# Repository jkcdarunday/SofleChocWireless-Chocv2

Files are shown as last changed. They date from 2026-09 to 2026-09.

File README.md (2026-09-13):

# Sofle Choc Wireless — Choc v2 PCB prototype

Revision: CV2-P1, 2026-09-13. Based on
[db-ok/SofleChocWireless](https://github.com/db-ok/SofleChocWireless/tree/aae7cc0ac5ca563dab8222320ae8749ed1911e56),
commit `aae7cc0ac5ca563dab8222320ae8749ed1911e56`.

This project modifies the reversible Sofle Choc Wireless PCB for Kailh Choc v2
(PG1353) switch mounting. The PCB, three switch footprint definitions, and
minimum track-width constraint have been changed. Nearby traces and vias have
been rerouted around the enlarged holes.

**This is an unbuilt prototype.** Connectivity passes KiCad's check, but the
board still has DRC findings described in `VALIDATION.md`. Review those findings
and test physical fit before ordering an assembled keyboard or a production run.

## AI-Generated Changes Disclosure

The changes in this fork were generated using ChatGPT 6 Astra Max and have not been independently reviewed or tested.

## Open the design

Extract the complete ZIP, then open:

`SofleChocWireless/PCB/SofleKeyboard.kicad_pro`

Use KiCad 7 or newer. The routed board is
`SofleChocWireless/PCB/SofleKeyboard.kicad_pcb`; the schematic is alongside it.
Keep the folder structure so the project-local library paths resolve. Standard
KiCad libraries may be needed to edit or replace other components. Footprints
are embedded in the PCB, including the revised switch geometry.

The source schematic is electrically unchanged. No firmware matrix changes are
required by these mechanical switch changes.

## PCB changes

| Feature | Revised geometry |
| --- | --- |
| Switch center hole | 5.0 mm nonplated hole at each of 30 positions per half |
| Fixing-pin relief | Two mirrored 1.5 × 2.0 mm nonplated slots per switch; 60 total |
| Ordinary switch slot centers | Local coordinates (−5, 5.15) and (5, 5.15) mm |
| Optional encoder-position switch SW25 | Slots at local (−5, −5.15) and (5, −5.15) mm, matching its reversed switch orientation |
| Minimum track width | 0.15 mm, with new route sections using this width |
| Copper clearance constraint | Existing 0.20 mm minimum retained |
| Hole clearance constraint | Existing 0.25 mm minimum retained |

The 3.4 mm switch center holes were enlarged. At the 29 ordinary hotswap
positions, the old small boss holes were replaced by the fixing-pin slots.
SW25 received the two slots as well. Slot orientation follows each footprint,
including the angled thumb switches. Both mirrored positions are included for
the reversible PCB.

Electrical pad positions, sizes, layers, net names, and component positions
match the original board. Routing changes affect nearby matrix, LED, and ground
connections. Copper zones were refilled after rerouting. Ground vias were moved,
added, or removed as needed to retain connectivity around the new holes.

The three updated library footprints are in
`SofleChocWireless/PCB/SofleChoc.pretty/`:

- `Choc_Hotswap_SK6812MiniE_BiggerHSPads.kicad_mod` — 25 placements.
- `Choc_Hotswap_SK6812MiniE_BiggerHSPads_Column1.kicad_mod` — 4 placements.
- `Kailh-PG1350-1u-reversible-SK6812MiniE_MODIFIED.kicad_mod` — SW25.

Their original names are retained so existing schematic and board references
continue to resolve. Other footprint variants in the bundled libraries were
not converted to Choc v2.

## Assembly and fabrication

The original 29 hotswap positions and optional switch/encoder position are
retained. The existing wireless controller, battery, display, encoder, and LED
circuits are retained.

The center-hole and fixing-slot geometry targets PG1353, with slot relief
cross-checked against the PG1353S drawing. Physical compatibility has not been
tested with either variant. Choc v1 fit is also unverified after replacing the
original boss holes.

The case and plate files are included unchanged as reference geometry. Check
plate thickness, switch retention, keycap clearance, and standoff heights
against the exact switch variant and keycaps you intend to use. The existing
plate file settings are not a Choc v2 assembly specification.

Choose a PCB process that supports the project's 0.15 mm traces and routed
nonplated slots. Review the remaining DRC findings, inspect both copper layers
around the switch openings, and regenerate Gerbers and drill files from this
modified board after review. Confirm that the drill output contains the slots.
No fabrication exports are included in this package.

Prototype checks should cover switch seating on both PCB orientations, hotswap
socket clearance, matrix operation, wireless power operation, and LED operation
under the intended load. These have not been physically tested.

## Design references

- [Upstream source and build guide](https://github.com/db-ok/SofleChocWireless/blob/aae7cc0ac5ca563dab8222320ae8749ed1911e56/docs/build_guide_choc_wireless.md).
- [Kailh PG1353 datasheet, archived by Keyboardio](https://github.com/keyboardio/keyswitch_documentation/blob/323ea47b7b90550327231fa311a2762b1308661a/datasheets/Kailh/CPG135301D02.pdf).
- [Kailh PG1353S datasheet](https://www.kailhswitch.com/uploads/15927/files/CPG1353S01D02-01-data-sheet.pdf).
- [ai03 PG1353 hotswap footprint cross-check](https://github.com/ai03-2725/MX_V2/blob/0b379eebbeb66c7fd6e82e400b47958ad695614e/Kailh_PG1353_Hotswap.pretty/Kailh-PG1353-Hotswap-1U.kicad_mod).

The upstream license is included in `LICENSE`.

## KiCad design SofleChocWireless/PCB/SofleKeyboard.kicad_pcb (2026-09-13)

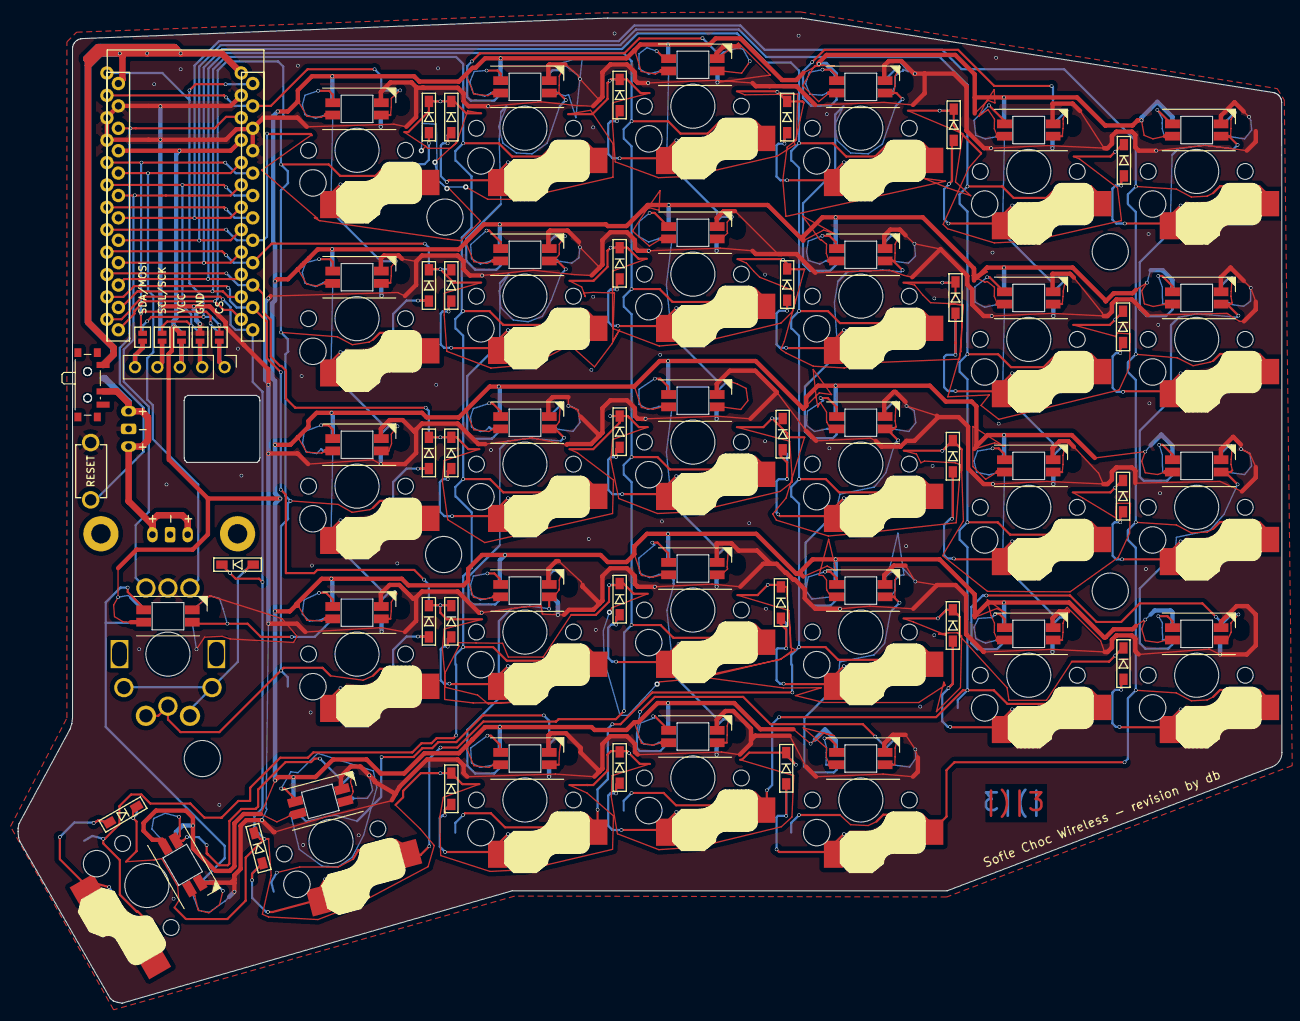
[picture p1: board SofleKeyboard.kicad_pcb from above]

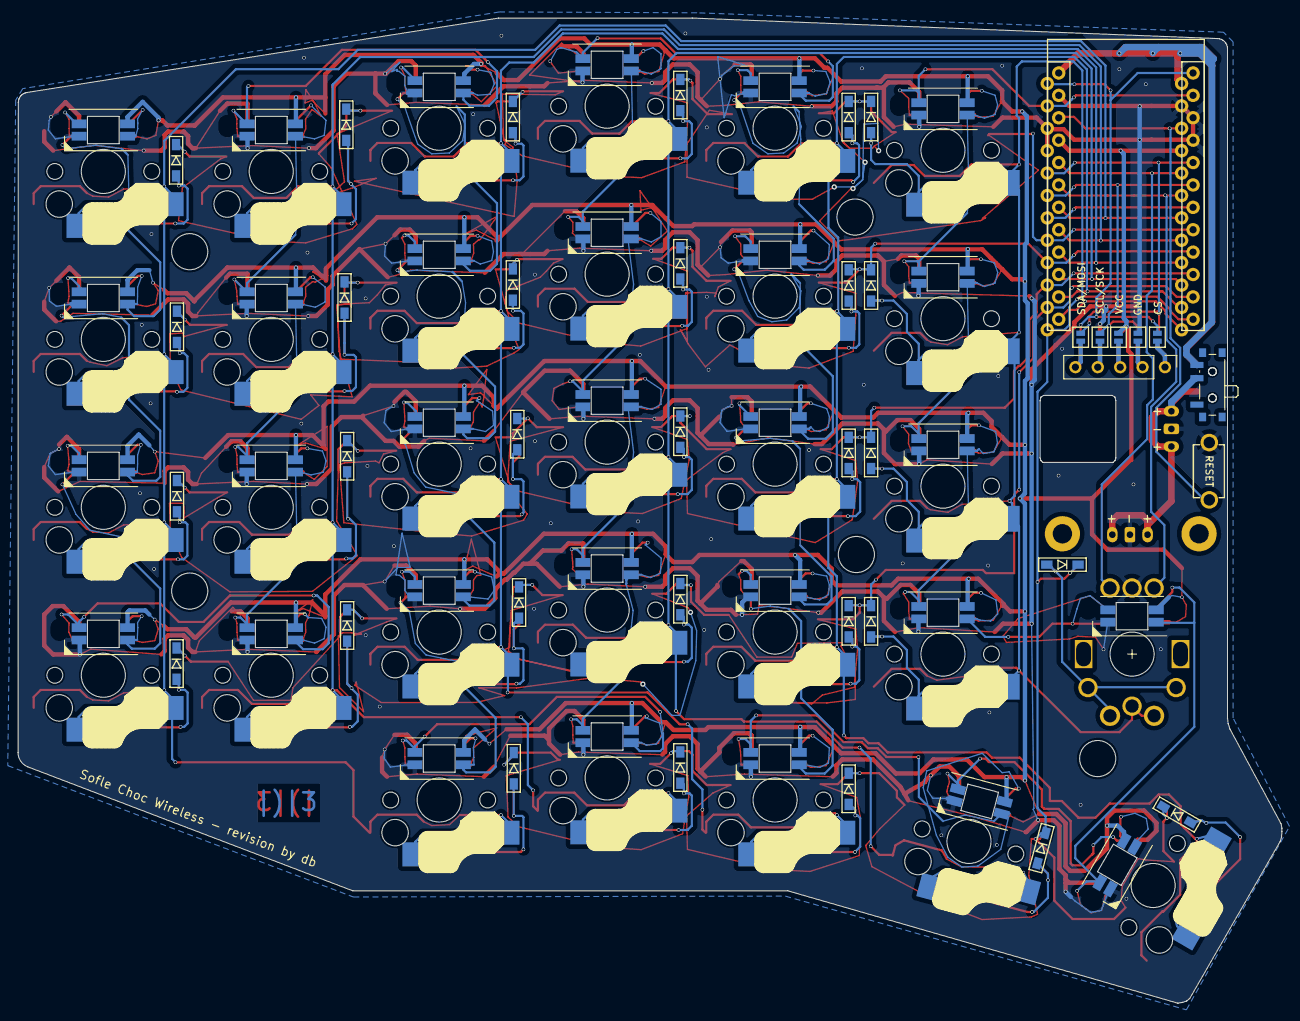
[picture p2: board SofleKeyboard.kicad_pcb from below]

Board: 2 copper layers, 143.4 x 111.8 mm, 85 parts (6 on the bottom side), 86 nets.

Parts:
D1, D2, D3, D4, D5, D6, D7, D8, D9, D10, D11, D12, D13, D14, D15, D16, D17, D18, D19, D20, D21, D22, D23, D24, D25, D26, D27, D28, D29, D30: D; crkbd-diode
J3: OLED; OLED_NICEVIEW_COMBO_HDR_5Pin
JP0, JP1, JP2, JP3, JP4, JP5, JP6, JP7, JP8, JP9: Jumper_NO_Small; Jumper_small
JST_BATT1, JST_BATT2: Conn_01x02; JST_PH_S2B-PH-K_1x02_P2.00mm_DoubleSided
RSW1: SW_RST; TACT_SWITCH_TVBP06
SW1, SW7, SW13, SW19: SW_PUSH_LED; Choc_Hotswap_SK6812MiniE_BiggerHSPads_Column1
SW2, SW3, SW4, SW5, SW6, SW8, SW9, SW10, SW11, SW12, SW14, SW15, SW16, SW17, SW18, SW20, SW21, SW22, SW23, SW24, SW26, SW27, SW28, SW29, SW30: SW_PUSH_LED; Choc_Hotswap_SK6812MiniE_BiggerHSPads
SW25: SW_PUSH_LED; Kailh-PG1350-1u-reversible-SK6812MiniE_MODIFIED
SW31: Rotary_Encoder_Switch; RotaryEncoder_Alps_EC11E-Switch_Vertical_H20mm-keebio_modif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
SW_BATT+1, SW_BATT+2: SW_SPST; SW_SPDT_PCM12
TH1, TH2: HOLE; M2_HOLE_PCB
TH3, TH4, TH5, TH6, TH7: HOLE; HOLE_M2_TH
U1: ProMicro

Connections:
CS: JP0.2, JP9.2, U1.1 (TX(PD3))
ENCA: SW31.A, U1.20 (A3(PF4))
ENCB: SW31.B, U1.19 (A2(PF5))
GND: JP1.2, JP8.2, JST_BATT1.1, JST_BATT2.1, RSW1.1, SW1.3 (GND), SW2.3 (GND), SW3.3 (GND), SW4.3 (GND), SW5.3 (GND), SW6.3 (GND), SW7.3 (GND), SW8.3 (GND), SW9.3 (GND), SW10.3 (GND), SW11.3 (GND), SW12.3 (GND), SW13.3 (GND), SW14.3 (GND), SW15.3 (GND), SW16.3 (GND), SW17.3 (GND), SW18.3 (GND), SW19.3 (GND), SW20.3 (GND), SW21.3 (GND), SW22.3 (GND), SW23.3 (GND), SW24.3 (GND), SW25.3 (GND), SW26.3 (GND), SW27.3 (GND), SW28.3 (GND), SW29.3 (GND), SW30.3 (GND), SW31.C, U1.3 (GND), U1.4 (GND), U1.23 (GND)
LED: SW1.4 (DIN), U1.2 (RX(PD2))
unnamed: D1.2 (A), SW1.5
unnamed: D2.2 (A), SW2.5
unnamed: D3.2 (A), SW3.5
unnamed: D4.2 (A), SW4.5
unnamed: D5.2 (A), SW5.5
unnamed: D6.2 (A), SW6.5
unnamed: D7.2 (A), SW7.5
unnamed: D8.2 (A), SW8.5
unnamed: D9.2 (A), SW9.5
unnamed: D10.2 (A), SW10.5
unnamed: D11.2 (A), SW11.5
unnamed: D12.2 (A), SW12.5
unnamed: D13.2 (A), SW13.5
unnamed: D14.2 (A), SW14.5
unnamed: D15.2 (A), SW15.5
unnamed: D16.2 (A), SW16.5
unnamed: D17.2 (A), SW17.5
unnamed: D18.2 (A), SW18.5
unnamed: D19.2 (A), SW19.5
unnamed: D20.2 (A), SW20.5
unnamed: D21.2 (A), SW21.5
unnamed: D22.2 (A), SW22.5
unnamed: D23.2 (A), SW23.5
unnamed: D24.2 (A), SW24.5
unnamed: D25.2 (A), SW25.6, SW31.S2
unnamed: D26.2 (A), SW26.5
unnamed: D27.2 (A), SW27.5
unnamed: D28.2 (A), SW28.5
unnamed: D29.2 (A), SW29.5
unnamed: D30.2 (A), SW30.5
unnamed: J3.1, JP4.1, JP9.1
unnamed: J3.2, JP3.1, JP8.1
unnamed: J3.3, JP2.1, JP7.1
unnamed: J3.4, JP1.1, JP6.1
unnamed: J3.5, JP0.1, JP5.1
unnamed: JST_BATT1.2, JST_BATT2.2, SW_BATT+1.2 (B), SW_BATT+2.2 (B)
unnamed: SW1.2 (DOUT), SW7.4 (DIN)
unnamed: SW2.2 (DOUT), SW3.4 (DIN)
unnamed: SW2.4 (DIN), SW8.2 (DOUT)
unnamed: SW3.2 (DOUT), SW9.4 (DIN)
unnamed: SW4.2 (DOUT), SW5.4 (DIN)
unnamed: SW4.4 (DIN), SW10.2 (DOUT)
unnamed: SW10.4 (DIN), SW16.2 (DOUT)
unnamed: SW11.2 (DOUT), SW17.4 (DIN)
unnamed: SW5.2 (DOUT), SW11.4 (DIN)
unnamed: SW6.4 (DIN), SW12.2 (DOUT)
unnamed: SW12.4 (DIN), SW18.2 (DOUT)
unnamed: SW13.2 (DOUT), SW19.4 (DIN)
unnamed: SW7.2 (DOUT), SW13.4 (DIN)
unnamed: SW8.4 (DIN), SW14.2 (DOUT)
unnamed: SW14.4 (DIN), SW20.2 (DOUT)
unnamed: SW15.2 (DOUT), SW21.4 (DIN)
unnamed: SW9.2 (DOUT), SW15.4 (DIN)
unnamed: SW16.4 (DIN), SW22.2 (DOUT)
unnamed: SW17.2 (DOUT), SW23.4 (DIN)
unnamed: SW18.4 (DIN), SW24.2 (DOUT)
unnamed: SW19.2 (DOUT), SW25.4 (DIN)
unnamed: SW20.4 (DIN), SW28.2 (DOUT)
unnamed: SW21.2 (DOUT), SW29.4 (DIN)
unnamed: SW22.4 (DIN), SW30.2 (DOUT)
unnamed: SW23.2 (DOUT), SW24.4 (DIN)
unnamed: SW25.2 (DOUT), SW26.4 (DIN)
unnamed: SW26.2 (DOUT), SW27.4 (DIN)
unnamed: SW27.2 (DOUT), SW28.4 (DIN)
unnamed: SW29.2 (DOUT), SW30.4 (DIN)
unnamed: SW_BATT+1.1 (A), SW_BATT+2.1 (A), U1.24 (RAW)
RESET: RSW1.2, U1.22 (RST)
SCL: JP3.2, JP6.2, U1.6 (SCL(PD0))
SDA: JP4.2, JP5.2, U1.5 (SDA(PD1))
VCC: JP2.2, JP7.2, SW1.1 (VDD), SW2.1 (VDD), SW3.1 (VDD), SW4.1 (VDD), SW5.1 (VDD), SW6.1 (VDD), SW7.1 (VDD), SW8.1 (VDD), SW9.1 (VDD), SW10.1 (VDD), SW11.1 (VDD), SW12.1 (VDD), SW13.1 (VDD), SW14.1 (VDD), SW15.1 (VDD), SW16.1 (VDD), SW17.1 (VDD), SW18.1 (VDD), SW19.1 (VDD), SW20.1 (VDD), SW21.1 (VDD), SW22.1 (VDD), SW23.1 (VDD), SW24.1 (VDD), SW25.1 (VDD), SW26.1 (VDD), SW27.1 (VDD), SW28.1 (VDD), SW29.1 (VDD), SW30.1 (VDD), U1.21 (VCC)
col0: SW6.6, SW12.6, SW18.6, SW24.6, SW30.6, U1.18 (A1(PF6))
col1: SW5.6, SW11.6, SW17.6, SW23.6, SW29.6, U1.17 (A0(PF7))
col2: SW4.6, SW10.6, SW16.6, SW22.6, SW28.6, U1.16 (D15(PB1))
col3: SW3.6, SW9.6, SW15.6, SW21.6, SW27.6, U1.15 (D14(PB3))
col4: SW2.6, SW8.6, SW14.6, SW20.6, SW26.6, U1.14 (D16(PB2))
col5: SW1.6, SW7.6, SW13.6, SW19.6, SW25.5, SW31.S1, U1.13 (D10(PB6))
row0: D1.1 (K), D2.1 (K), D3.1 (K), D4.1 (K), D5.1 (K), D6.1 (K), U1.8 (D5(PC6))
row1: D7.1 (K), D8.1 (K), D9.1 (K), D10.1 (K), D11.1 (K), D12.1 (K), U1.9 (D6(PD7))
row2: D13.1 (K), D14.1 (K), D15.1 (K), D16.1 (K), D17.1 (K), D18.1 (K), U1.10 (D7(PE6))
row3: D19.1 (K), D20.1 (K), D21.1 (K), D22.1 (K), D23.1 (K), D24.1 (K), U1.11 (D8(PB4))
row4: D25.1 (K), D26.1 (K), D27.1 (K), D28.1 (K), D29.1 (K), D30.1 (K), U1.12 (D9(PB5))

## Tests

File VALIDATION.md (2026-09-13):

# Validation of CV2-P1

Native KiCad 7.0.11 was used to load the board, refill both copper zones, and
generate DRC reports. The upstream baseline was checked with refilled zones
for comparison. Full reports are included in `validation/`.

The final board has **zero unconnected pads** and no reported copper-clearance,
copper-edge-clearance, track-width, dangling-track, or dangling-via violations.
This does not mean the whole board is DRC-clean.

## DRC comparison

| KiCad finding | Upstream baseline | Modified board |
| --- | ---: | ---: |
| Solder-mask bridge | 186 | 184 |
| Footprint type mismatch | 59 | 59 |
| Hole clearance | 58 | 58 |
| Library footprint issues | 42 | 42 |
| Silkscreen edge clearance | 4 | 35 |
| Starved thermal | 6 | 5 |
| Library footprint mismatch | 3 | 3 |
| Co-located holes | 2 | 2 |
| **Total DRC findings** | **360** | **388** |
| **Unconnected pads** | **0** | **0** |

The 31 additional silkscreen-clearance warnings arise where the fixing-pin
slots approach or intersect existing footprint silkscreen. Review and trim
that silkscreen before fabrication.

The baseline also contains hole-clearance and solder-mask findings around the
reversible switch/socket footprints, plus footprint metadata and library
findings. Some referenced libraries were not available to the validation
environment. Matching or reduced category counts do not constitute a waiver
of those findings; inspect the exact report locations. No findings have been
hidden through added DRC exclusions for this revision.

## Static source checks

The modified board was parsed and compared with the upstream source:

- All 30 switch centers have 5.0 mm nonplated holes.
- All 30 positions have two correctly located 1.5 × 2.0 mm nonplated slots.
- Electrical pad positions, sizes, layers, and net names are unchanged.
- Component positions are unchanged.
- The project minimum track width is 0.15 mm.

The original board has 85 footprints, 3,070 track segments, 418 vias, and two
copper zones. The modified board has 85 footprints, 3,540 track segments,
415 vias, and two copper zones. Segment counts reflect rerouting and splitting
of paths; they are not an electrical performance measurement.

`validation/static-design-checks.json` records these results and the SHA-256
digest of the final PCB. `SHA256SUMS.txt` records the packaged file hashes.

## Limits

The design has not been fabricated or physically assembled. Switch fit, plate
retention, cap clearance, LED current capacity, and complete keyboard operation
remain untested. ERC, an independent schematic-to-PCB netlist audit, and
manufacturing drill-output review are not included in this validation. The
source comparison confirms preservation of the upstream electrical pad/net
assignments, not the correctness of the original circuit.

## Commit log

2026-09-13 Add support for PG1353 and PG1353s
    [SofleKeyboard.kicad_pcb]
2026-11-10 Add Choc v2 center-hole adaptation and fabrication files
2026-11-10 Show PCB render in hole-only README
2026-11-10 Show bare PCB front and back in hole-only README
2026-11-10 Arrange PCB previews as left and right keyboard halves
2026-11-10 Link silent-pin variant from hole-only README
